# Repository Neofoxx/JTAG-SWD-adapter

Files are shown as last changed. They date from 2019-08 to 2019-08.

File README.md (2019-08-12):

# JTAG-SWD-adapter
Universal JTAG/SWD/UART adapter based on FT2232H

#### PCB view
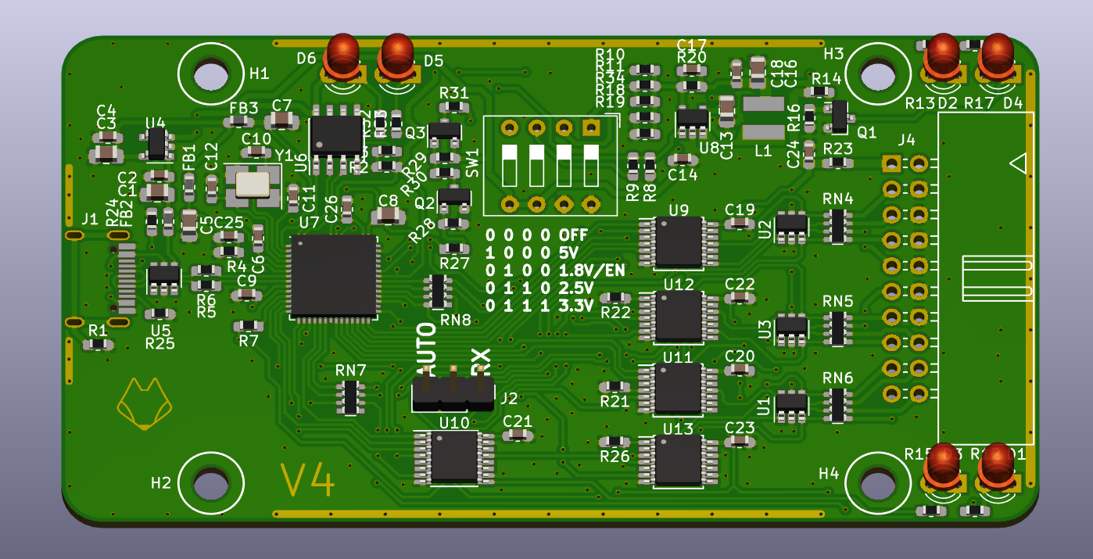
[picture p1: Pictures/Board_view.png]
PCB view


#### Finished product
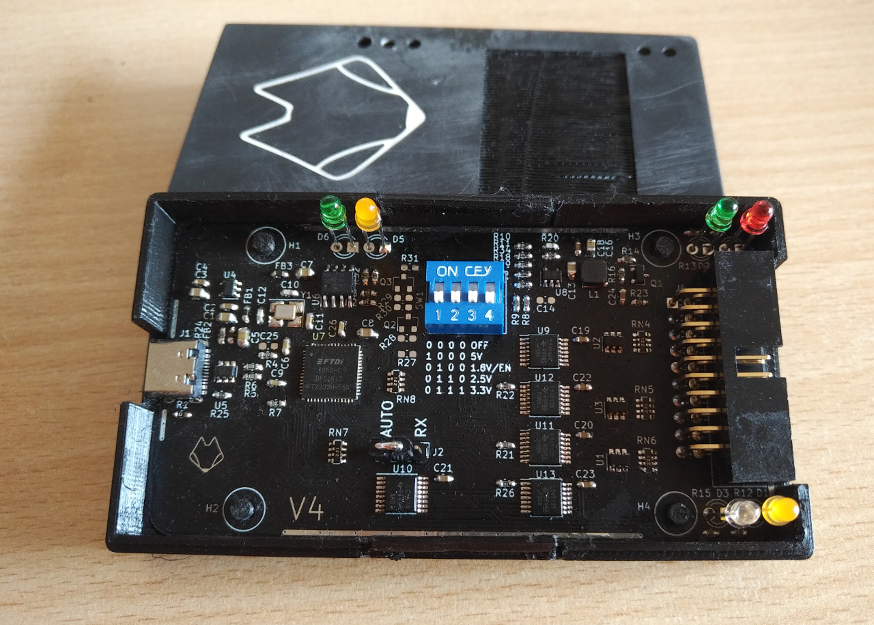
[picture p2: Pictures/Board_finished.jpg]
Finished view


### Pinout
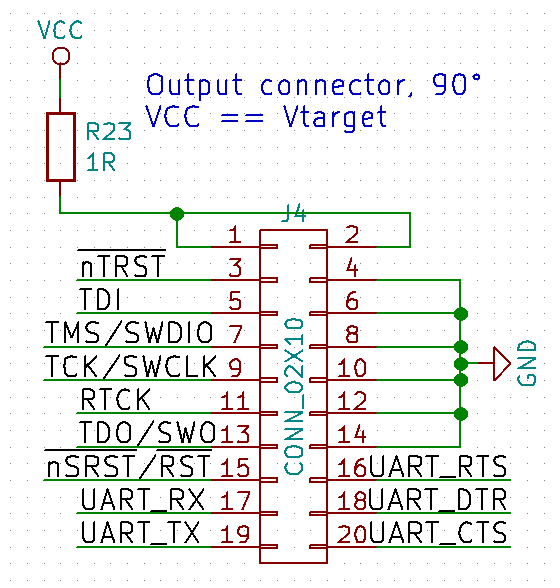
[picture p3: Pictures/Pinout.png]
Pinout


## Description
This is a universal JTAG/SWD/UART/SPI/... adapter based around the FT2232H chip.
This initially started based off the KT-Link specifications, but has since evolved into the following set of features:

- USB Type-C connector
- 1.8V - 5V traget supply
- JTAG and SWD support on channel A, UART support on channel B.
- ESD protection of USB and of target
- Integrated power section, to power target from the adapter (5V/3.3V/2.5V/1.8V available)
- Similar pinout to the standard found on commercial JTAG/SWD adapters, with the addition of UART pins
- JTAG/SWD programming with simultaneous UART communication
- LEDs for USB power, Target power, SWD interface, Activity, and RX&TX of the UART

The design has been tested and confirmed working with OpenOCD.
Tested targets so far have been STM32F1 (SWD), STM32F3 (SWD), ESP32 (JTAG), and PIC32MX (JTAG)

## Component selection & BOM

Components were selected based on the desire to try them out, usually based on price/performance. FT2232H and its support circuitry should not be changed, but other things (series resistors, LEDs, DCDC chip) can be changed & exprimented with without issue.

## Setup (1/2) - EEPROM

After soldering the board together and verifying for no shorts, plug the debugger into your computer, and verify that it shows up. With no parameters in the EEPROM, it should show up as a generic FT2232H Dual UART device.

You can find the relevant files in the Setup folder.

### Windows

Use the provided "Neofoxx FT-Prog template.xml".
- Connect the device to your computer. Verify that VCP drivers for FT2232H are installed
- Open FT-Prog. Click on "Devices" -> "Scan and Parse"
- The device should now show up
- Right clock on your device, and select "Apply template". Choose the template in the first step.
- Afterwards, right-click on the device again, and select "Program". Confirm again that you want to progam the device.
- After programming, unplug & re-plug your device. Wait for driver installation.
- In FT-Prog, perform another "Scan and Parse".
- Confirm the device has the proper parameters.
- Success!

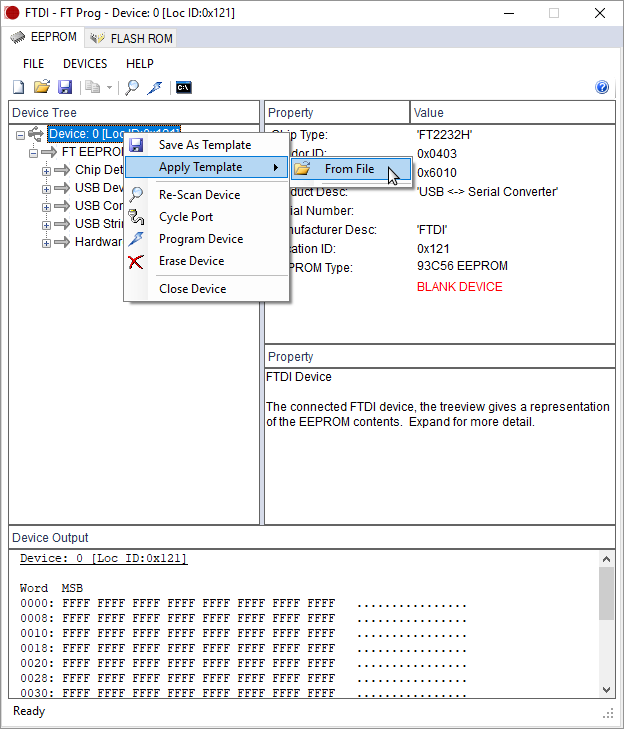
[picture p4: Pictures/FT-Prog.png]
FT-Prog


### Linux

- Use the provided "Neofoxx_ftdi_eeprom.conf". 
- (Feel free to change the serial number, but do not increase the number of characters)
- Install/build libftdi1 from https://www.intra2net.com/en/developer/libftdi/download.php
- (Link for reference, if you run into trouble: https://www.acmesystems.it/CM3-HOME_ft4232_setup )
- Flash the eeprom with the following command: `ftdi_eeprom --device i:0x0403:0x6010 --flash-eeprom Neofoxx_ftdi_eeprom.conf`
- Run the command again. Afterwards, unplug & re-plug the device.
- With dmesg or similar, you can check that the attached device now has the proper Manufacturer and Description string 
- Alternatively, in the examples folder, run the `eeprom` utility, and see what it outputs.

#### Known issues

- FT-Prog and ftdi_eeprom do not write 100% identical settings. The adapter will work nonetheless.
- If flashed with ftdi_eeprom, then checked in FT-Prog, the device will LOSE ITS PARAMETERS. In that case, upload them again in FT-Prog. If you don't check it in FT-Prog, it will work in Windows just fine. (Possible issue, that ftdi_eeprom doesn't write the eeprom type?)
- If you manage to mangle the parameters, and your VID/PID is suddenly 0000:0000, you can revive the device with a Windows box (virtualization won't work, unless you can pass a device with 0000:0000 to it).
- -> Connect the device to a Windows box, and force install the VCP drivers on the "Unknown device"
- -> This should then allow you to see the device in FT-Prog, and allow you to erase the eeprom and flash it with the proper parameters.

## Setup (2/2) - OpenOCD settings

- Copy the neofoxx.cfg file into your openocd scripts/interface/ftdi/ folder.

### Linux

- Done!

### Windows

- If you want to use the adapter with OpenOCD under Windows, you will have to change its drievr from the FTDI one a WinUSB one.
- Download zadig from here: https://zadig.akeo.ie/
- Run the tool.
- If necessary, in the Options menu, select "List All Devices"
- Select "Neofoxx JTAG/SWD adapter (Interface 0)"
- Select WinUSB, then click Replace Driver.
- Done!
- Note, if you have multiple adapters connected at the same time and want to use them, you have to do this on all of them.
- If the adapter suddenly stops working under Windows, fist check if the driver has changed. Windows have a nasty habit of changing things without telling you.

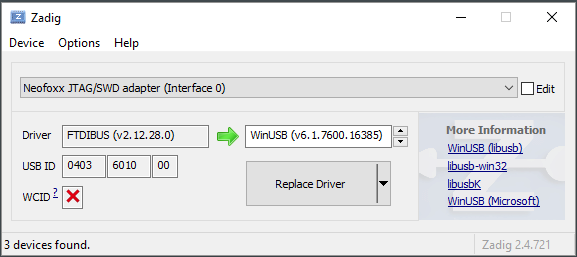
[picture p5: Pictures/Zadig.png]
Zadig


## Normal operation and things to look out for

- To use SWD with this board, you need to pass the proper flags to OpenOCD. Try something like this `openocd -f interface/ftdi/neofoxx.cfg -c "transport select swd" -f target/stm32f1x.cfg -c "adapter_khz 1000"`
- Because the board is compliant to the standard pinout, it will, when used in SWD mode, connect the TDO line to the RX of the UART channel, to be used as SWO.
- -> If this is undesired, the jumper on the board can be moved from "Auto" to "RX". This way, the UART RX pin will always be the RX pin, bypassing the switching of pins.
- The adapter includes a power section to power the target
- -> The maximum current draw is limited with a 1 ohm resistor, to protect the PC.
- -> When changing voltages, first turn the EN/1.8V pin to off, then set the voltage, then enable it again.
- -> When using 5V, disable the EN/1.8V switch first (the other two do not matter), then enable the 5V switch. Also in this case, if you make a mistake and short a high voltage onto the VTarget rail, your computer is at risk. There is some protection, but it's your computer. If you suspect this might happen, replace the 1 ohm resistor with an SMD fuse.
- The USB/Power LED shines when the USB cable is plugged in (5V is present)
- The VTarget LED shines when the voltage on VTarget is over 0.7V
- The SWD LED shines when the SWD interface is selected
- The Acivity light is SW driven from OpenOCD or others.

## Housing
The housing has been designed with latches, so it can be quickly opened and closed. 3D printing with PLA has given the best results so far.
Be warned, the housing was designed with minimal tolerances, so it might be a snug fit.

## Future improvements:

- Possibly split the two Vtarget pins into two separate pins - possibility of powering the target with say 5V, while communication works on 1.8V, etc.
- Instead of rounded corners, use inverted rounded corners, or no rounding at all. This would reduce waste during production of PCBs, since they could be panelized more easily (just V-cut, no mouse bites required)
- Fixup ftdi_eeprom & FT-Prog differences
- Update schematic to newer version of KiCad, and not use rescue symbols.
- Test the power section & enabling via the FTDI. As it is, that is UNTESTED

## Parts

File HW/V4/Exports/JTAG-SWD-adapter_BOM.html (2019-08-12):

Ref | Qnty | Value | Part | Footprint | Description | Vendor
C1, C3, C5, C7, C8 | 5 | 4u7 | Device:C | Capacitor_SMD:C_0805_2012Metric_Pad1.15x1.40mm_HandSolder | Unpolarized capacitor
C2, C4, C6, C9, C11, C14, C18, C19, C20, C21, C22, C23, C24, C26 | 14 | 100nF | Device:C | Capacitor_SMD:C_0603_1608Metric_Pad1.05x0.95mm_HandSolder | Unpolarized capacitor
C10, C12 | 2 | 27pF | Device:C | Capacitor_SMD:C_0603_1608Metric_Pad1.05x0.95mm_HandSolder | Unpolarized capacitor
C13, C16 | 2 | 4.7uF | Device:C | Capacitor_SMD:C_0805_2012Metric_Pad1.15x1.40mm_HandSolder | Unpolarized capacitor
C17, C25 | 2 | DNS | Device:C | Capacitor_SMD:C_0603_1608Metric_Pad1.05x0.95mm_HandSolder | Unpolarized capacitor
D1, D2, D3, D4, D5, D6 | 6 | LED | JTAG-SWD-adapter-rescue:LED | LED_THT:LED_D3.0mm
FB1, FB3 | 2 | 600R, 1A | Device:Ferrite_Bead_Small | Inductor_SMD:L_0603_1608Metric_Pad1.05x0.95mm_HandSolder | Ferrite bead, small symbol
FB2 | 1 | 220R, 2.5A | Device:Ferrite_Bead_Small | Inductor_SMD:L_0603_1608Metric_Pad1.05x0.95mm_HandSolder | Ferrite bead, small symbol
H1, H2, H3, H4 | 4 | MountingHole | Mechanical:MountingHole | MountingHole:MountingHole_3.2mm_M3 | Mounting Hole without connection
J1 | 1 | USB_C_Receptacle_USB2.0 | Connector:USB_C_Receptacle_USB2.0 | KiCAD library:Jing USB C 2.0 16pin receptable | USB 2.0-only Type-C Receptacle connector
J2 | 1 | Conn_01x03_Male | Connector:Conn_01x03_Male | Connector_PinHeader_2.54mm:PinHeader_1x03_P2.54mm_Vertical | Generic connector, single row, 01x03, script generated (kicad-library-utils/schlib/autogen/connector/)
J4 | 1 | CONN_02X10 | JTAG-SWD-adapter-rescue:CONN_02X10 | Connector_Multicomp:Multicomp_MC9A22-2034_2x10_P2.54mm_Horizontal
L1 | 1 | 1.5uH | Device:L | KiCAD library:SMNR4018_(1616FPS) | Inductor
MARK1 | 1 | LOGO | KiCAD library symbols:LOGO | KiCAD library:FOX_LOGO_MASK
Q1, Q2 | 2 | BC847 | Transistor_BJT:BC847 | Package_TO_SOT_SMD:SOT-23 | 0.1A Ic, 45V Vce, NPN Transistor, SOT-23
Q3 | 1 | BC857 | Transistor_BJT:BC857 | Package_TO_SOT_SMD:SOT-23 | 0.1A Ic, 45V Vce, PNP Transistor, SOT-23
R1 | 1 | 0R | Device:R | Resistor_SMD:R_0603_1608Metric_Pad1.05x0.95mm_HandSolder | Resistor
R2, R7, R27, R30 | 4 | 10k | Device:R | Resistor_SMD:R_0603_1608Metric_Pad1.05x0.95mm_HandSolder | Resistor
R3 | 1 | 2k | Device:R | Resistor_SMD:R_0603_1608Metric_Pad1.05x0.95mm_HandSolder | Resistor
R4 | 1 | 12k | Device:R | Resistor_SMD:R_0603_1608Metric_Pad1.05x0.95mm_HandSolder | Resistor
R5, R6 | 2 | 10R | Device:R | Resistor_SMD:R_0603_1608Metric_Pad1.05x0.95mm_HandSolder | Resistor
R8, R14, R16, R28, R29 | 5 | 100k | Device:R | Resistor_SMD:R_0603_1608Metric_Pad1.05x0.95mm_HandSolder | Resistor
R9, R12, R13, R15, R17, R21, R22, R26, R31, R32, R33 | 11 | 1k | JTAG-SWD-adapter-rescue:R | Resistor_SMD:R_0603_1608Metric_Pad1.05x0.95mm_HandSolder
R10 | 1 | 180k | JTAG-SWD-adapter-rescue:R | Resistor_SMD:R_0603_1608Metric_Pad1.05x0.95mm_HandSolder
R11 | 1 | 470k | JTAG-SWD-adapter-rescue:R | Resistor_SMD:R_0603_1608Metric_Pad1.05x0.95mm_HandSolder
R18, R19, R20 | 3 | 220k | JTAG-SWD-adapter-rescue:R | Resistor_SMD:R_0603_1608Metric_Pad1.05x0.95mm_HandSolder
R23 | 1 | 1R | Device:R | Resistor_SMD:R_0603_1608Metric_Pad1.05x0.95mm_HandSolder | Resistor
R24, R25 | 2 | 5k1 | Device:R | Resistor_SMD:R_0603_1608Metric_Pad1.05x0.95mm_HandSolder | Resistor
R34 | 1 | 330k | JTAG-SWD-adapter-rescue:R | Resistor_SMD:R_0603_1608Metric_Pad1.05x0.95mm_HandSolder
RN1, RN2, RN3 | 3 | 4x470k | JTAG-SWD-adapter-rescue:R_Pack04 | Resistor_SMD:R_Array_Convex_4x0603
RN4, RN5, RN6, RN7, RN8 | 5 | 4x220R | JTAG-SWD-adapter-rescue:R_Pack04 | Resistor_SMD:R_Array_Convex_4x0603
SW1 | 1 | SW_DIP_x04 | Switch:SW_DIP_x04 | Button_Switch_THT:SW_DIP_SPSTx04_Slide_9.78x12.34mm_W7.62mm_P2.54mm | 4x DIP Switch, Single Pole Single Throw (SPST) switch, small symbol
U1, U2, U3, U5 | 4 | SRV05-4 | Power_Protection:SRV05-4 | Package_TO_SOT_SMD:SOT-23-6 | ESD Protection Diodes with Low Clamping Voltage, SOT-23-6
U4 | 1 | LN1134A332MR-G | Regulator_Linear:AP2112K-3.3 | Package_TO_SOT_SMD:SOT-23-5 | 600mA low dropout linear regulator, with enable pin, 3.8V-6V input voltage range, 3.3V fixed positive output, SOT-23-5 package
U6 | 1 | 93LCxxB | Memory_EEPROM:93LCxxB | Package_SO:SOIC-8_3.9x4.9mm_P1.27mm | Serial EEPROM, 93 Series, 2.5V, DIP-8/SOIC-8
U7 | 1 | FT2232H-56Q | KiCAD library symbols:FT2232H-56Q | Package_DFN_QFN:QFN-56-1EP_8x8mm_P0.5mm_EP5.6x5.6mm
U8 | 1 | BL8028 | KiCAD library symbols:BL8028 | Package_TO_SOT_SMD:SOT-23-5
U9, U11, U12, U13 | 4 | 74LVC125 | 74xx:74LVC125 | Package_SO:TSSOP-14_4.4x5mm_P0.65mm | Quad buffer 3-State outputs
U10 | 1 | 74LVC157A | JTAG-SWD-adapter-rescue:74LS157-RESCUE-JTAG-SWD-adapter | Package_SO:TSSOP-16_4.4x5mm_P0.65mm
Y1 | 1 | 12MHz | Device:Crystal_GND24 | Crystal:Crystal_SMD_3225-4Pin_3.2x2.5mm_HandSoldering | Four pin crystal, GND on pins 2 and 4

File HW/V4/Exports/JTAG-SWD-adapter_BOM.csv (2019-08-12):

Source: | /home/neofoxx/Projects/HW/JTAG-SWD-adapter/HW/V4/JTAG-SWD-adapter.sch
Date: | ned 11 avg 2019 10:19:47 CEST
Tool: | Eeschema 5.0.2-bee76a0~70~ubuntu18.04.1
Generator: | /usr/share/kicad/plugins/bom_csv_grouped_by_value_with_fp.py
Component Count: | 103
Ref | Qnty | Value | Cmp name | Footprint | Description | Vendor
C1, C3, C5, C7, C8, | 5 | 4u7 | C | Capacitor_SMD:C_0805_2012Metric_Pad1.15x1.40mm_HandSolder | Unpolarized capacitor
C12, C10, | 2 | 27pF | C | Capacitor_SMD:C_0603_1608Metric_Pad1.05x0.95mm_HandSolder | Unpolarized capacitor
C16, C13, | 2 | 4.7uF | C | Capacitor_SMD:C_0805_2012Metric_Pad1.15x1.40mm_HandSolder | Unpolarized capacitor
C24, C2, C4, C6, C9, C11, C26, C18, C14, C20, C19, C23, C22, C21, | 14 | 100nF | C | Capacitor_SMD:C_0603_1608Metric_Pad1.05x0.95mm_HandSolder
C25, C17, | 2 | DNS | C | Capacitor_SMD:C_0603_1608Metric_Pad1.05x0.95mm_HandSolder | Unpolarized capacitor
D1, D2, D4, D3, D5, D6, | 6 | LED | LED | LED_THT:LED_D3.0mm
FB1, FB3, | 2 | 600R, 1A | Ferrite_Bead_Small | Inductor_SMD:L_0603_1608Metric_Pad1.05x0.95mm_HandSolder | Ferrite bead, small symbol
FB2, | 1 | 220R, 2.5A | Ferrite_Bead_Small | Inductor_SMD:L_0603_1608Metric_Pad1.05x0.95mm_HandSolder | Ferrite bead, small symbol
H1, H2, H4, H3, | 4 | MountingHole | MountingHole | MountingHole:MountingHole_3.2mm_M3 | Mounting Hole without connection
J1, | 1 | USB_C_Receptacle_USB2.0 | USB_C_Receptacle_USB2.0 | KiCAD library:Jing USB C 2.0 16pin receptable | USB 2.0-only Type-C Receptacle connector
J2, | 1 | Conn_01x03_Male | Conn_01x03_Male | Connector_PinHeader_2.54mm:PinHeader_1x03_P2.54mm_Vertical | Generic connector, single row, 01x03, script generated (kicad-library-utils/schlib/autogen/connector/)
J4, | 1 | CONN_02X10 | CONN_02X10 | Connector_Multicomp:Multicomp_MC9A22-2034_2x10_P2.54mm_Horizontal
L1, | 1 | 1.5uH | L | KiCAD library:SMNR4018_(1616FPS) | Inductor
MARK1, | 1 | LOGO | LOGO | KiCAD library:FOX_LOGO_MASK
Q1, Q2, | 2 | BC847 | BC847 | Package_TO_SOT_SMD:SOT-23 | 0.1A Ic, 45V Vce, NPN Transistor, SOT-23
Q3, | 1 | BC857 | BC857 | Package_TO_SOT_SMD:SOT-23 | 0.1A Ic, 45V Vce, PNP Transistor, SOT-23
R1, | 1 | 0R | R | Resistor_SMD:R_0603_1608Metric_Pad1.05x0.95mm_HandSolder | Resistor
R3, | 1 | 2k | R | Resistor_SMD:R_0603_1608Metric_Pad1.05x0.95mm_HandSolder | Resistor
R4, | 1 | 12k | R | Resistor_SMD:R_0603_1608Metric_Pad1.05x0.95mm_HandSolder | Resistor
R6, R5, | 2 | 10R | R | Resistor_SMD:R_0603_1608Metric_Pad1.05x0.95mm_HandSolder | Resistor
R7, R2, R30, R27, | 4 | 10k | R | Resistor_SMD:R_0603_1608Metric_Pad1.05x0.95mm_HandSolder | Resistor
R10, | 1 | 180k | R | Resistor_SMD:R_0603_1608Metric_Pad1.05x0.95mm_HandSolder
R11, | 1 | 470k | R | Resistor_SMD:R_0603_1608Metric_Pad1.05x0.95mm_HandSolder
R12, R13, R17, R15, R32, R33, R9, R31, R21, R22, R26, | 11 | 1k | R | Resistor_SMD:R_0603_1608Metric_Pad1.05x0.95mm_HandSolder
R14, R16, R8, R29, R28, | 5 | 100k | R | Resistor_SMD:R_0603_1608Metric_Pad1.05x0.95mm_HandSolder | Resistor
R20, R18, R19, | 3 | 220k | R | Resistor_SMD:R_0603_1608Metric_Pad1.05x0.95mm_HandSolder
R23, | 1 | 1R | R | Resistor_SMD:R_0603_1608Metric_Pad1.05x0.95mm_HandSolder | Resistor
R24, R25, | 2 | 5k1 | R | Resistor_SMD:R_0603_1608Metric_Pad1.05x0.95mm_HandSolder | Resistor
R34, | 1 | 330k | R | Resistor_SMD:R_0603_1608Metric_Pad1.05x0.95mm_HandSolder
RN1, RN2, RN3, | 3 | 4x470k | R_Pack04 | Resistor_SMD:R_Array_Convex_4x0603
RN6, RN5, RN4, RN7, RN8, | 5 | 4x220R | R_Pack04 | Resistor_SMD:R_Array_Convex_4x0603
SW1, | 1 | SW_DIP_x04 | SW_DIP_x04 | Button_Switch_THT:SW_DIP_SPSTx04_Slide_9.78x12.34mm_W7.62mm_P2.54mm | 4x DIP Switch, Single Pole Single Throw (SPST) switch, small symbol
U2, U3, U1, U5, | 4 | SRV05-4 | SRV05-4 | Package_TO_SOT_SMD:SOT-23-6 | ESD Protection Diodes with Low Clamping Voltage, SOT-23-6
U4, | 1 | LN1134A332MR-G | AP2112K-3.3 | Package_TO_SOT_SMD:SOT-23-5 | 600mA low dropout linear regulator, with enable pin, 3.8V-6V input voltage range, 3.3V fixed positive output, SOT-23-5 package
U6, | 1 | 93LCxxB | 93LCxxB | Package_SO:SOIC-8_3.9x4.9mm_P1.27mm | Serial EEPROM, 93 Series, 2.5V, DIP-8/SOIC-8
U7, | 1 | FT2232H-56Q | FT2232H-56Q | Package_DFN_QFN:QFN-56-1EP_8x8mm_P0.5mm_EP5.6x5.6mm
U8, | 1 | BL8028 | BL8028 | Package_TO_SOT_SMD:SOT-23-5
U9, U11, U12, U13, | 4 | 74LVC125 | 74LVC125 | Package_SO:TSSOP-14_4.4x5mm_P0.65mm | Quad buffer 3-State outputs
U10, | 1 | 74LVC157A | 74LS157-RESCUE-JTAG-SWD-adapter | Package_SO:TSSOP-16_4.4x5mm_P0.65mm
Y1, | 1 | 12MHz | Crystal_GND24 | Crystal:Crystal_SMD_3225-4Pin_3.2x2.5mm_HandSoldering | Four pin crystal, GND on pins 2 and 4

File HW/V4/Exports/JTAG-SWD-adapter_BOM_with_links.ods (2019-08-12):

Source: | /home/neofoxx/Projects/HW/JTAG-SWD-adapter/HW/V4/JTAG-SWD-adapter.sch
Date: | ned 11 avg 2019 10:19:47 CEST
Tool: | Eeschema 5.0.2-bee76a0~70~ubuntu18.04.1
Generator: | /usr/share/kicad/plugins/bom_csv_grouped_by_value_with_fp.py
Component Count: | 103 |  |  | Components are listed as they are used on prototypes
Ref | Qnty | Value | Description | Link
C1, C3, C5, C7, C8, | 5 | 4u7 | Capacitor, 0805 | https://lcsc.com/product-detail/Multilayer-Ceramic-Capacitors-MLCC-SMD-SMT_SAMSUNG_CL21A475KAQNNNE_4-7uF-475-10-25V_C1779.html
C12, C10, | 2 | 27pF | Capacitor, 0603 | https://lcsc.com/product-detail/Others_Murata-Electronics-GRM1885C1H270FA01D_C162215.html
C16, C13, | 2 | 4.7uF | Capacitor, 0805 | https://lcsc.com/product-detail/Multilayer-Ceramic-Capacitors-MLCC-SMD-SMT_SAMSUNG_CL21A475KAQNNNE_4-7uF-475-10-25V_C1779.html
C24, C2, C4, C6, C9, C11, C26, C18, C14, C20, C19, C23, C22, C21, | 14 | 100nF | Capacitor, 0603 | https://lcsc.com/product-detail/Multilayer-Ceramic-Capacitors-MLCC-SMD-SMT_SAMSUNG_CL10B104KB8NNNC_100nF-104-10-50V_C1591.html
C25, C17, | 2 | DNS | Capacitor, 0603
D1, D2, D4, D3, D5, D6, | 6 | LED | 3mm through hole LED | Any 3mm LED with matte lens (clear works too, just doesn’t look as nice)
FB1, FB3, | 2 | 600R, 1A | Ferrite bead, 0603 | https://lcsc.com/product-detail/Ferrite-Beads-And-Chips_TDK_MPZ1608S601ATA00_600R-25-at100MHz_C107335.html
FB2, | 1 | 220R, 2.5A | Ferrite bead, 0603 | https://lcsc.com/product-detail/Ferrite-Beads-And-Chips_muRata_BLM18SG221TN1D_220R-25_C88988.html
J1, | 1 | USB_C_Receptacle_USB2.0 | USB C connector | https://lcsc.com/product-detail/USB-Type-C_MC-311D_C136423.html
J2, | 1 | Conn_01x03_Male | 3-pin header | Any pin header + jumper
J4, | 1 | CONN_02X10 | 20pin header, 90° | https://www.tme.eu/en/details/t821-1-20-r1/idc-connectors/amphenol/t821120a1r100ceu/
L1, | 1 | 1.5uH | Coil for DCDC | https://lcsc.com/product-detail/Power-Inductors_Shun-Xiang-Nuo-Elec-SMNR4018-1R5MT_C135252.html
Q1, Q2, | 2 | BC847 | NPN transistor | https://uk.farnell.com/on-semiconductor/bc847blt3g/transistor-bipol-npn-45v-sot-23/dp/2533307
Q3, | 1 | BC857 | PNP transistor | https://uk.farnell.com/on-semiconductor/bc857blt1g/transistor-pnp-sot-23/dp/1459044
R1, | 1 | 0R | Resistor, 0603 | https://uk.farnell.com/multicomp/mcwr06x000-ptl/res-0r0-0-1w-jumper/dp/2447743
R3, | 1 | 2k | Resistor, 0603 | https://lcsc.com/product-detail/Chip-Resistor-Surface-Mount_2KR-2001-1_C105576.html
R4, | 1 | 12k | Resistor, 0603 | https://lcsc.com/product-detail/Chip-Resistor-Surface-Mount_12KR-1202-1_C114659.html
R6, R5, | 2 | 10R | Resistor, 0603 | https://uk.farnell.com/multicomp/mcmr06x10r0ftl/res-10r-1-0-1w-0603-ceramic/dp/2073361
R7, R2, R30, R27, | 4 | 10k | Resistor, 0603 | https://lcsc.com/product-detail/Chip-Resistor-Surface-Mount_10KR-1002-1_C98220.html
R10, | 1 | 180k | Resistor, 0603 | https://lcsc.com/product-detail/Chip-Resistor-Surface-Mount_Uniroyal-Elec-0603WAF1803T5E_C22827.html
R11, | 1 | 470k | Resistor, 0603 | https://lcsc.com/product-detail/Chip-Resistor-Surface-Mount_470KR-4703-1_C114622.html
R12, R13, R17, R15, R32, R33, R9, R31, R21, R22, R26, | 11 | 1k | Resistor, 0603 | https://lcsc.com/product-detail/Chip-Resistor-Surface-Mount_1KR-1001-1_C22548.html
R14, R16, R8, R29, R28, | 5 | 100k | Resistor, 0603 | https://lcsc.com/product-detail/Chip-Resistor-Surface-Mount_100KR-1003-1_C14675.html
R20, R18, R19, | 3 | 220k | Resistor, 0603 | https://lcsc.com/product-detail/Chip-Resistor-Surface-Mount_220KR-220K-1_C123420.html
R23, | 1 | 1R | Resistor, 0603 | https://uk.farnell.com/multicomp/mcwr06w1r00ftl/res-1r-1-0-1w-0603-thick-film/dp/2447289
R24, R25, | 2 | 5k1 | Resistor, 0603 | https://lcsc.com/product-detail/Chip-Resistor-Surface-Mount_5-1KR-5101-1_C105580.html
R34, | 1 | 330k | Resistor, 0603 | https://lcsc.com/product-detail/Chip-Resistor-Surface-Mount_330KR-3303-1_C114618.html
RN1, RN2, RN3, | 3 | 4x470k | Resistor, 4*0603 | https://lcsc.com/product-detail/Resistor-Networks-Arrays_Uniroyal-Elec-4D03WGJ0474T5E_C12026.html
RN6, RN5, RN4, RN7, RN8, | 5 | 4x220R | Resistor, 4*0603 | https://lcsc.com/product-detail/Resistor-Networks-Arrays_Uniroyal-Elec-4D03WGJ0221T5E_C29719.html
SW1, | 1 | SW_DIP_x04 | Dip switch, though hole, 4 position | https://lcsc.com/product-detail/DIP-Switches_Dongguan-Guangzhu-Industrial-Dongguan-Guangzhu-Industrial-Dongguan-Guangzhu-Industrial-DIP-switch-Dip-Switch-DSWB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
U2, U3, U1, U5, | 4 | SRV05-4 | ESD diodes | https://lcsc.com/product-detail/TVS_SRV05-4_C127538.html
U4, | 1 | LN1134A332MR-G | 3.3V Linear regulator | https://lcsc.com/product-detail/Low-Dropout-Regulators-LDO_NATLINEAR-LN1134A332MR-G_C141419.html
U6, | 1 | 93LCxxB | EEPROM | https://uk.farnell.com/microchip/93lc56b-i-sn/serial-eeprom-2kbit-2mhz-soic/dp/9758259
U7, | 1 | FT2232H-56Q | FTDI chip | https://uk.farnell.com/ftdi/ft2232h-56q-reel/interface-bridge-usb-uart-fifo/dp/2535722
U8, | 1 | BL8028 | DCDC step-down | https://lcsc.com/product-detail/DC-DC-Converters_Shanghai-Belling-BL8028CB5TR_C266177.html
U9, U11, U12, U13, | 4 | SN74LV4T125 | Voltage translators | https://uk.farnell.com/texas-instruments/sn74lv4t125pwr/buffer-translator-3-state-o-p/dp/3006795
U10, | 1 | SN74LVC157A | Mux chip | https://uk.farnell.com/texas-instruments/sn74lvc157apw/ic-data-selector-mux-74lvc157/dp/9592717
Y1, | 1 | 12MHz | Crystal | https://uk.farnell.com/multicomp/mcsjk-7u-12-00-10-10-80-b-10/crystal-12mhz-10pf-3-2mm-x-2-5mm/dp/2853914

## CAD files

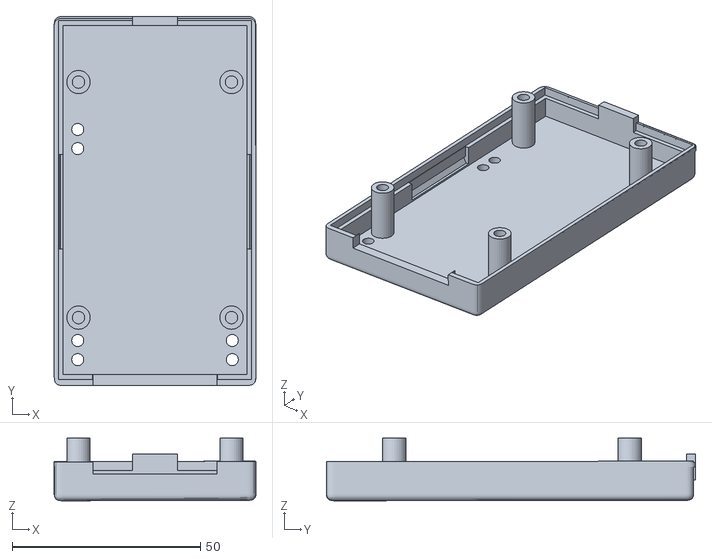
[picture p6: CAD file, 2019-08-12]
Housing/V4/Exports/ProgBox-Case_top.stl
53.6 x 97.9 x 16.6

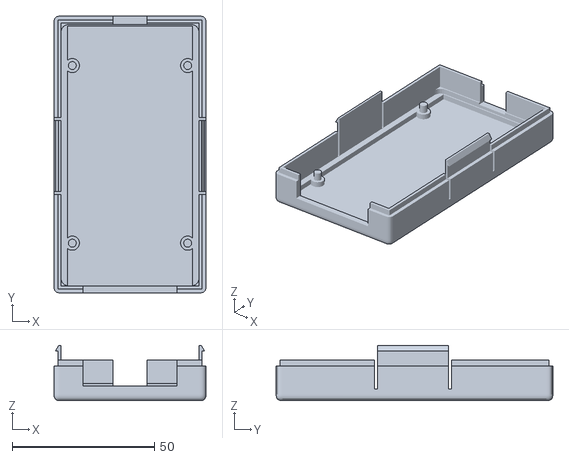
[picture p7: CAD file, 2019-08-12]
Housing/V4/Exports/ProgBox-Case_bottom.stl
53.5 x 97.4 x 19.5

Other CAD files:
Housing/V4/ProgBox.blend

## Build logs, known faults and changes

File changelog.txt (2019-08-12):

V1:

- An add-on board for the FT2232H-56Q Mini-Module
- Includes only voltage translators, series/pull-down resistors and status LEDs

Changelog for V2:

- V2 was never finished.
- Idea was to add ESD protection, and a PowerSupply stage
-- ESD - quad ESD diodes, for 5V max.
-- Power supply - 600mA Step-down DCDC, 5V/3.3V/2.5V/1.8V options.
-- Selectable through DIP switched on the inside.

Changes from V2 to V3:

- Raw FT2232 chip
- ESD now SRV05-4 instead of PGB1010603 (3pF instead of 0.4pF)
- USB C CONNECTOR!
- Through hole LEDs - saves a fortune on light guides
- Added open soldermask on select edges - should help with ESD
- Power supply section added for powering the target
- Most resistors changed to resistor array (4x0603)

Changelog for V4:

- DCDC converter in the power supply changed to a more suitable one.
- Fixed wiriing error on the USB connector
- Added status LEDs for the second UART channel (RX&TX LEDs)
- Removed dual footprints for the EEPROM

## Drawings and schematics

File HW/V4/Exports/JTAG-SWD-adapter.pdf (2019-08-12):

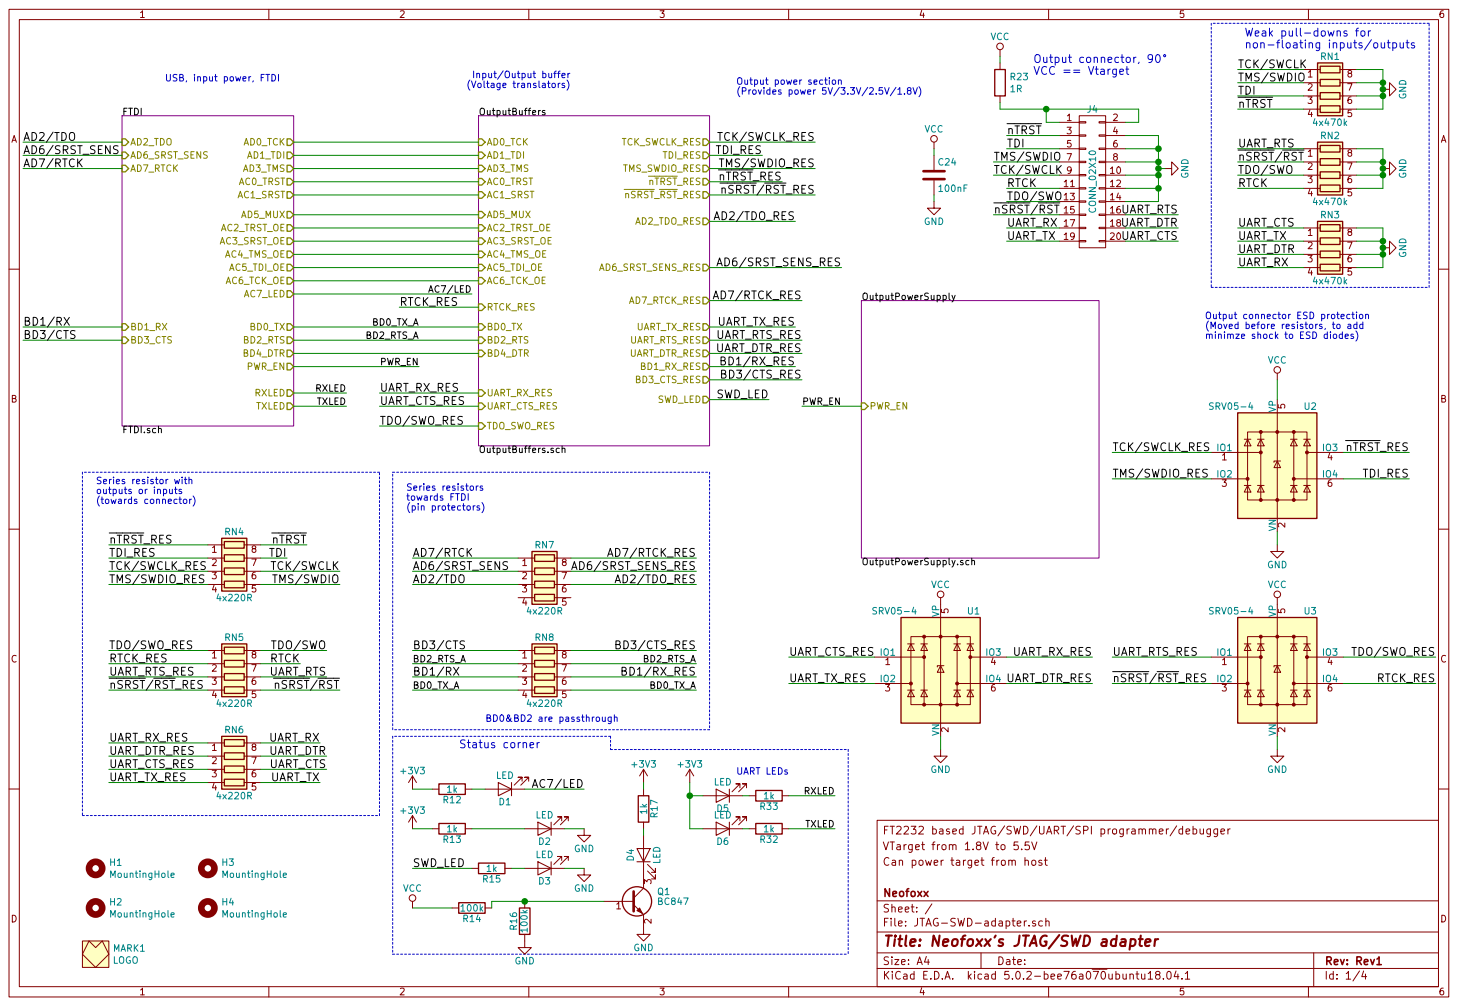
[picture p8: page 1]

Weak pull-downs for

TDI TMS/SWDIO | 1

TDI_RES

BD2_RTS_A | UART_RTS_RES

(Moved before resistors, to add
minimze shock to ESD diodes)

UART_DTR_RES

Series resistors
towards FTDI (pin protectors)

FT2232 based JTAG/SWD/UART/SPI programmer/debugger
VTarget from 1.8V to 5.5V
File: JTAG-SWD-adapter.sch Sheet: / Neofoxx Can power target from host

Id: 1/4 Title: Neofoxx's JTAG/SWD adapter

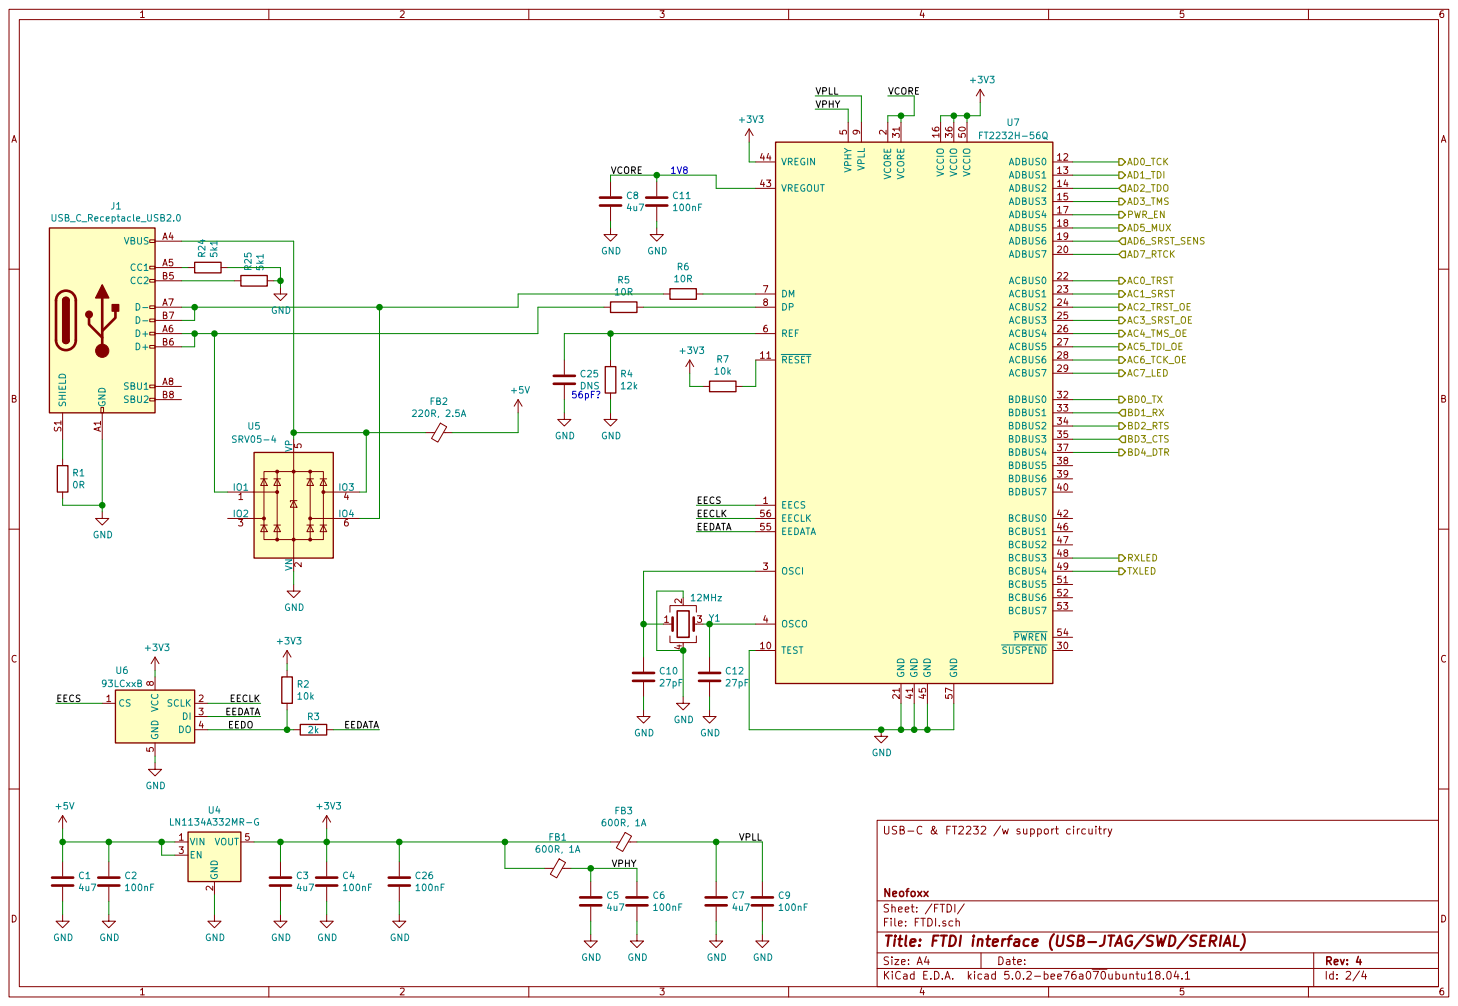
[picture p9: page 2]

Id: 2/4 Title: FTDI interface (USB-JTAG/SWD/SERIAL) File: FTDI.sch Sheet: /FTDI/ Neofoxx USB-C & FT2232 /w support circuitry R1
0R GND

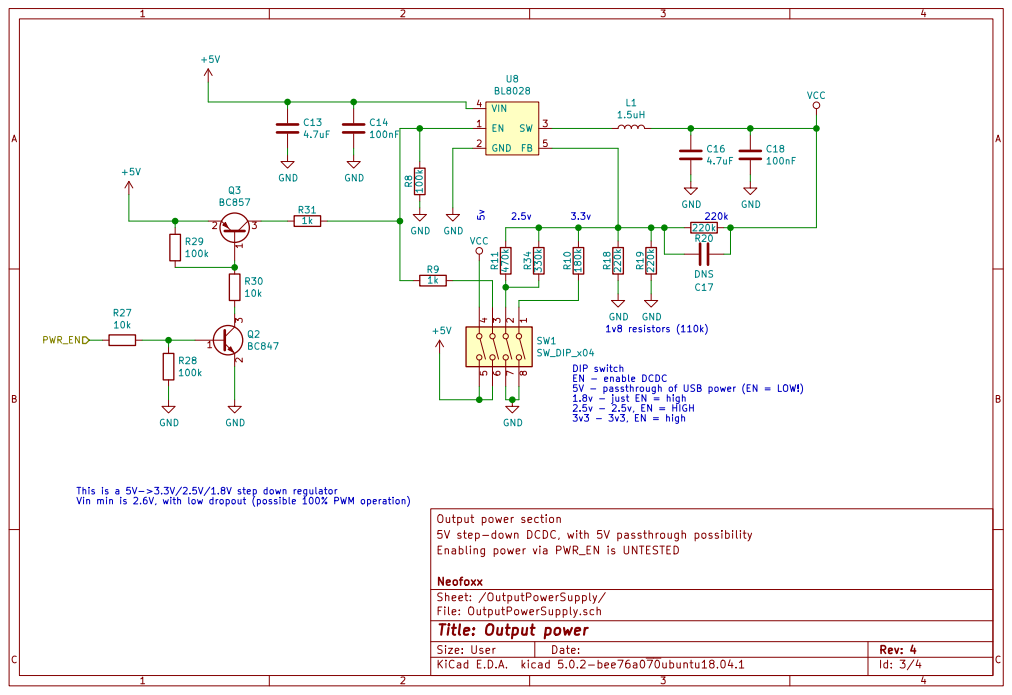
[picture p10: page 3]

8 SW1 SW_DIP_x04 R8 100k GND GND GND GND GND

Vin min is 2.6V, with low dropout (possible 100% PWM operation) 1

DIP switch EN - enable DCDC
5V - passthrough of USB power (EN = LOW!)
1.8v - just EN = high
2.5v - 2.5v, EN = HIGH
3v3 - 3v3, EN = high

This is a 5V->3.3V/2.5V/1.8V step down regulator

Output power section
5V step-down DCDC, with 5V passthrough possibility
Sheet: /OutputPowerSupply/ Neofoxx Enabling power via PWR_EN is UNTESTED

File: OutputPowerSupply.sch
Id: 3/4 Title: Output power

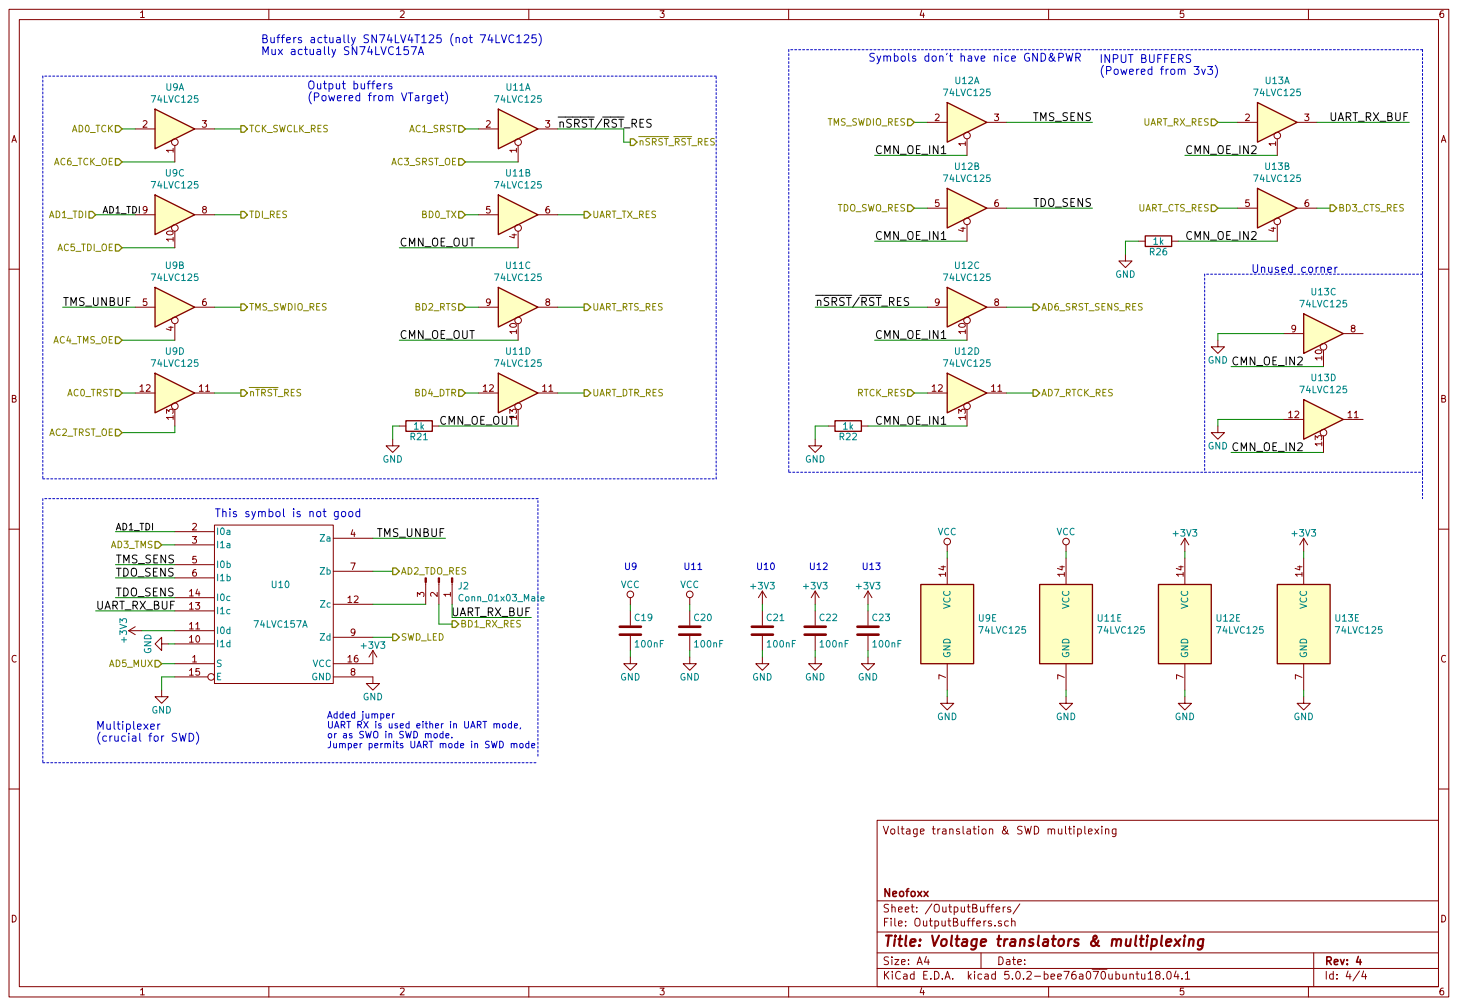
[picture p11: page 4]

Added jumper UART RX is used either in UART mode, or as SWO in SWD mode. Jumper permits UART mode in SWD mode

File: OutputBuffers.sch
Id: 4/4 Title: Voltage translators & multiplexing

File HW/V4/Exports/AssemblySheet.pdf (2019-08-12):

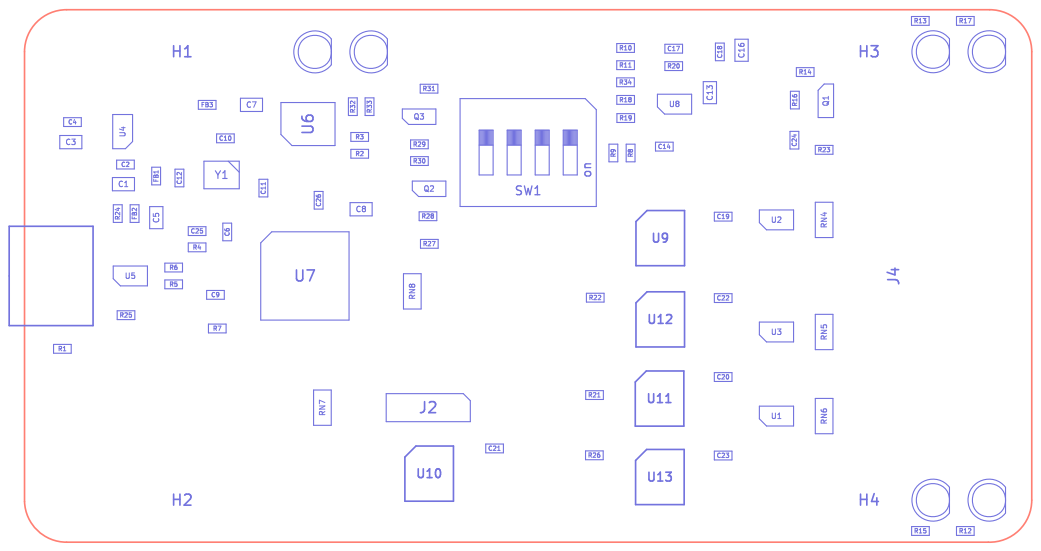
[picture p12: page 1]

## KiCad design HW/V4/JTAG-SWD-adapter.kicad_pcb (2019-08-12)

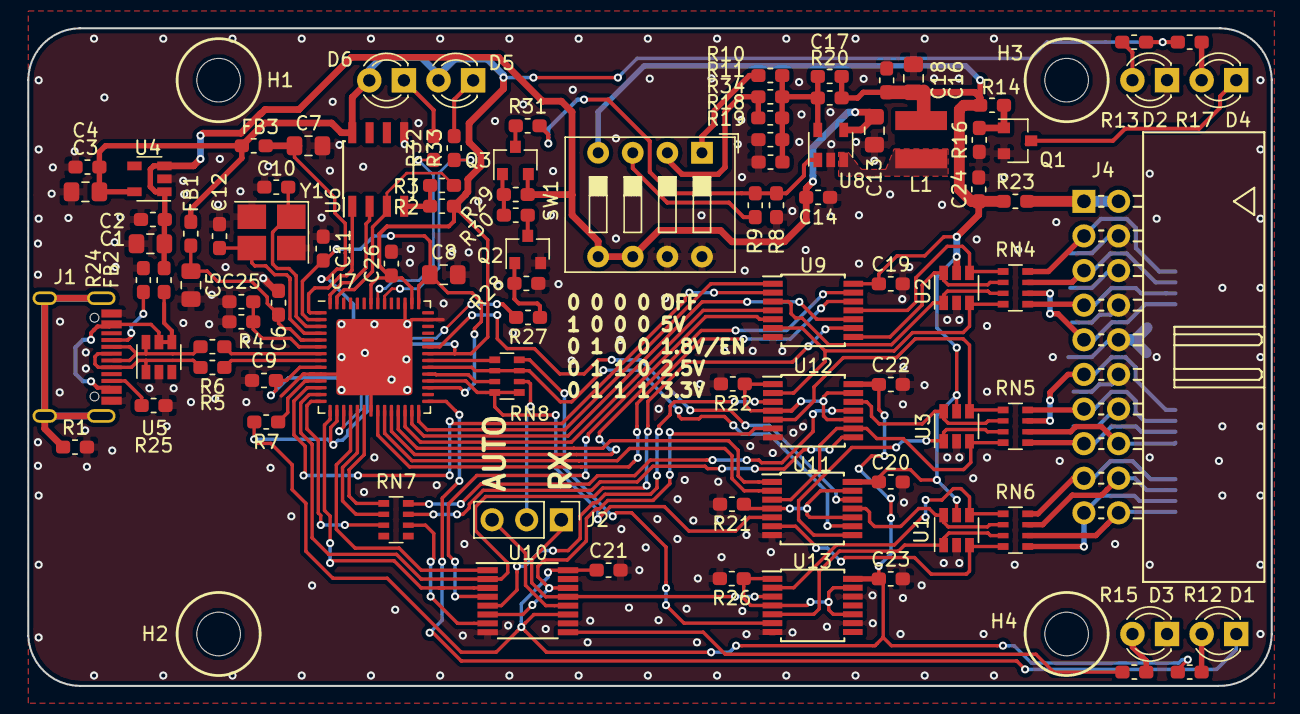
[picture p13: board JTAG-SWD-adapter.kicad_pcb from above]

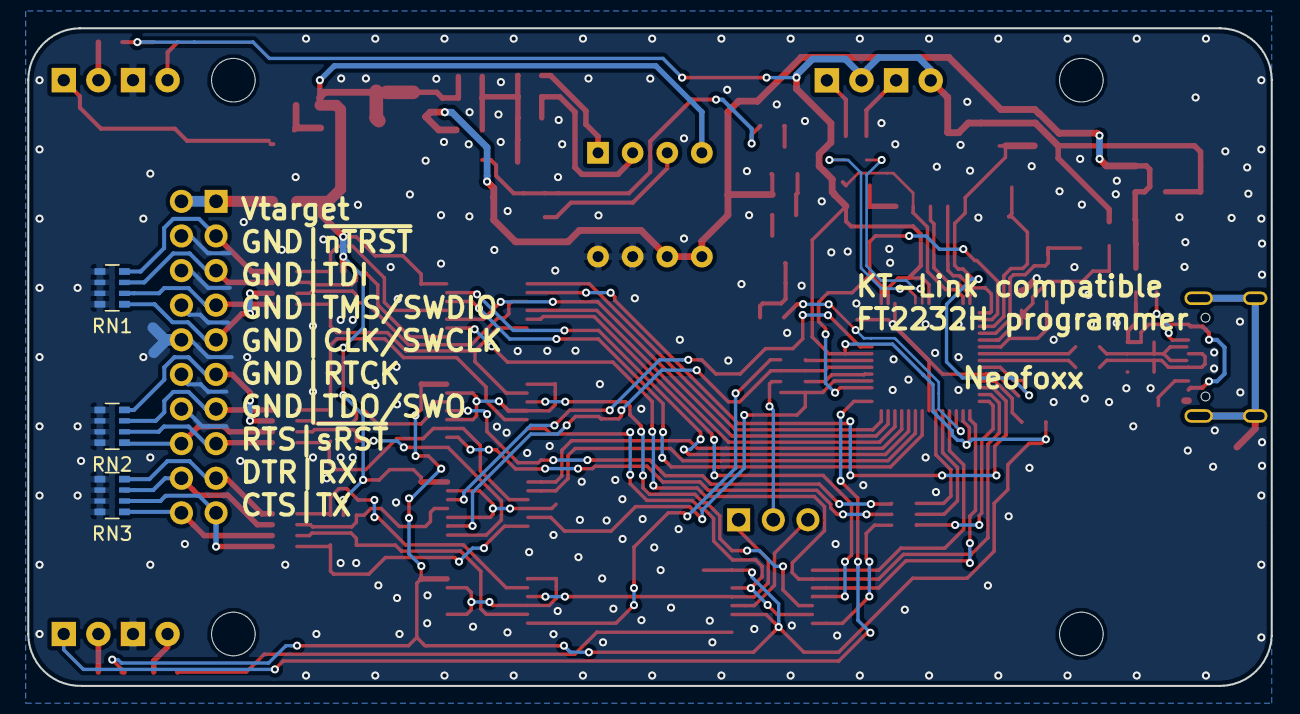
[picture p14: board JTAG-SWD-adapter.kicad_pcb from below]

Board: 2 copper layers, 91.2 x 48.3 mm, 103 parts (3 on the bottom side), 103 nets.

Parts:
C1, C3, C5, C7, C8: 4u7; C_0805_2012Metric_Pad1.15x1.40mm_HandSolder
C2, C4, C6, C9, C11, C14, C18, C19, C20, C21, C22, C23, C24, C26: 100nF; C_0603_1608Metric_Pad1.05x0.95mm_HandSolder
C10, C12: 27pF; C_0603_1608Metric_Pad1.05x0.95mm_HandSolder
C13, C16: 4.7uF; C_0805_2012Metric_Pad1.15x1.40mm_HandSolder
C17, C25: DNS; C_0603_1608Metric_Pad1.05x0.95mm_HandSolder
D1, D2, D3, D4, D5, D6: LED; LED_D3.0mm
FB1, FB3: 600R, 1A; L_0603_1608Metric_Pad1.05x0.95mm_HandSolder
FB2: 220R, 2.5A; L_0603_1608Metric_Pad1.05x0.95mm_HandSolder
H1, H2, H3, H4: MountingHole; MountingHole_3.2mm_M3
J1: USB_C_Receptacle_USB2.0; Jing USB C 2.0 16pin receptable
J2: Conn_01x03_Male; PinHeader_1x03_P2.54mm_Vertical
J4: CONN_02X10; Multicomp_MC9A22-2034_2x10_P2.54mm_Horizontal
L1: 1.5uH; SMNR4018_(1616FPS)
MARK1: LOGO; FOX_LOGO_MASK
Q1, Q2: BC847; SOT-23
Q3: BC857; SOT-23
R1: 0R; R_0603_1608Metric_Pad1.05x0.95mm_HandSolder
R2, R7, R27, R30: 10k; R_0603_1608Metric_Pad1.05x0.95mm_HandSolder
R3: 2k; R_0603_1608Metric_Pad1.05x0.95mm_HandSolder
R4: 12k; R_0603_1608Metric_Pad1.05x0.95mm_HandSolder
R5, R6: 10R; R_0603_1608Metric_Pad1.05x0.95mm_HandSolder
R8, R14, R16, R28, R29: 100k; R_0603_1608Metric_Pad1.05x0.95mm_HandSolder
R9, R12, R13, R15, R17, R21, R22, R26, R31, R32, R33: 1k; R_0603_1608Metric_Pad1.05x0.95mm_HandSolder
R10: 180k; R_0603_1608Metric_Pad1.05x0.95mm_HandSolder
R11: 470k; R_0603_1608Metric_Pad1.05x0.95mm_HandSolder
R18, R19, R20: 220k; R_0603_1608Metric_Pad1.05x0.95mm_HandSolder
R23: 1R; R_0603_1608Metric_Pad1.05x0.95mm_HandSolder
R24, R25: 5k1; R_0603_1608Metric_Pad1.05x0.95mm_HandSolder
R34: 330k; R_0603_1608Metric_Pad1.05x0.95mm_HandSolder
RN1, RN2, RN3: 4x470k; R_Array_Convex_4x0603
RN4, RN5, RN6, RN7, RN8: 4x220R; R_Array_Convex_4x0603
SW1: SW_DIP_x04; SW_DIP_SPSTx04_Slide_9.78x12.34mm_W7.62mm_P2.54mm
U1, U2, U3, U5: SRV05-4; SOT-23-6
U4: LN1134A332MR-G; SOT-23-5
U6: 93LCxxB; SOIC-8_3.9x4.9mm_P1.27mm
U7: FT2232H-56Q; QFN-56-1EP_8x8mm_P0.5mm_EP5.6x5.6mm
U8: BL8028; SOT-23-5
U9, U11, U12, U13: 74LVC125; TSSOP-14_4.4x5mm_P0.65mm
U10: 74LVC157A; TSSOP-16_4.4x5mm_P0.65mm
Y1: 12MHz; Crystal_SMD_3225-4Pin_3.2x2.5mm_HandSoldering

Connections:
+3V3: C3.1, C4.1, C21.1, C22.1, C23.1, C26.1, D5.2, D6.2, FB1.2, FB3.2, R2.1, R7.2, R12.2, R13.2, R17.1, U4.5, U6.8, U7.16, U7.36, U7.44, U7.50, U10.11, U10.16, U12.14, U13.14
+5V: C1.1, C2.1, C13.1, C14.1, FB2.1, Q3.2, R29.1, SW1.5, SW1.6, U4.1, U4.3, U8.4
/AC7/LED: D1.1, U7.29
/AD2/TDO: RN7.3, U7.14
/AD2/TDO_RES: RN7.6, U10.7
/AD6/SRST_SENS: RN7.2, U7.19
/AD6/SRST_SENS_RES: RN7.7, U12.8
/AD7/RTCK: RN7.1, U7.20
/AD7/RTCK_RES: RN7.8, U12.11
/BD0_TX_A: RN8.4, RN8.5, U7.32, U11.5
/BD1/RX: RN8.3, U7.33
/BD1/RX_RES: J2.2, RN8.6
/BD2_RTS_A: RN8.2, RN8.7, U7.34, U11.9
/BD3/CTS: RN8.1, U7.35
/BD3/CTS_RES: RN8.8, U13.6
/FTDI/AC0_TRST: U7.22, U9.12
/FTDI/AC1_SRST: U7.23, U11.2
/FTDI/AC2_TRST_OE: U7.24, U9.13
/FTDI/AC3_SRST_OE: U7.25, U11.1
/FTDI/AC4_TMS_OE: U7.26, U9.4
/FTDI/AC5_TDI_OE: U7.27, U9.10
/FTDI/AC6_TCK_OE: U7.28, U9.1
/FTDI/AD0_TCK: U7.12, U9.2
/FTDI/AD1_TDI: U7.13, U9.9, U10.2
/FTDI/AD3_TMS: U7.15, U10.3
/FTDI/AD5_MUX: U7.18, U10.1
/FTDI/BD4_DTR: U7.37, U11.12
/FTDI/EECLK: U6.2, U7.56
/FTDI/EECS: U6.1, U7.1
/FTDI/EEDATA: R3.1, U6.3, U7.55
/FTDI/EEDO: R2.2, R3.2, U6.4
/FTDI/VCORE: C8.1, C11.1, U7.2, U7.31, U7.43
/FTDI/VPHY: C5.1, C6.1, FB1.1, U7.5
/FTDI/VPLL: C7.1, C9.1, FB3.1, U7.9
/OutputBuffers/CMN_OE_IN1: R22.1, U12.1, U12.4, U12.10, U12.13
/OutputBuffers/CMN_OE_IN2: R26.1, U13.1, U13.4, U13.10, U13.13
/OutputBuffers/CMN_OE_OUT: R21.1, U11.4, U11.10, U11.13
/OutputBuffers/TDO_SENS: U10.6, U10.14, U12.6
/OutputBuffers/TMS_SENS: U10.5, U12.3
/OutputBuffers/TMS_UNBUF: U9.5, U10.4
/OutputBuffers/UART_RX_BUF: J2.1, U10.13, U13.3
/PWR_EN: R27.2, U7.17
/RTCK: J4.11, RN2.4, RN5.7
/RTCK_RES: RN5.2, U3.6, U12.12
/RXLED: R33.1, U7.48
/SWD_LED: R15.2, U10.9
/TCK/SWCLK: J4.9, RN1.1, RN4.6
/TCK/SWCLK_RES: RN4.3, U2.1, U9.3
/TDI: J4.5, RN1.3, RN4.7
/TDI_RES: RN4.2, U2.6, U9.8
/TDO/SWO: J4.13, RN2.3, RN5.8
/TDO/SWO_RES: RN5.1, U3.4, U12.5
/TMS/SWDIO: J4.7, RN1.2, RN4.5
/TMS/SWDIO_RES: RN4.4, U2.3, U9.6, U12.2
/TXLED: R32.1, U7.49
/UART_CTS: J4.20, RN3.1, RN6.6
/UART_CTS_RES: RN6.3, U1.1, U13.5
/UART_DTR: J4.18, RN3.3, RN6.7
/UART_DTR_RES: RN6.2, U1.6, U11.11
/UART_RTS: J4.16, RN2.1, RN5.6
/UART_RTS_RES: RN5.3, U3.1, U11.8
/UART_RX: J4.17, RN3.4, RN6.8
/UART_RX_RES: RN6.1, U1.4, U13.2
/UART_TX: J4.19, RN3.2, RN6.5
/UART_TX_RES: RN6.4, U1.3, U11.6
/~nSRST~/~RST~: J4.15, RN2.2, RN5.5
/~nSRST~/~RST~_RES: RN5.4, U3.3, U11.3, U12.9
/~nTRST~: J4.3, RN1.4, RN4.8
/~nTRST~_RES: RN4.1, U2.4, U9.11
GND: C1.2, C2.2, C3.2, C4.2, C5.2, C6.2, C7.2, C8.2, C9.2, C10.2, C11.2, C12.2, C13.2, C14.2, C16.2, C18.2, C19.2, C20.2, C21.2, C22.2, C23.2, C24.2, C25.2, C26.2, D2.1, D3.1, J1.A1, J4.4, J4.6, J4.8, J4.10, J4.12, J4.14, Q1.2, Q2.2, R1.2, R4.2, R8.1, R16.1, R18.1, R19.1, R21.2, R22.2, R24.2, R25.2, R26.2, R28.2, RN1.5, RN1.6, RN1.7, RN1.8, RN2.5, RN2.6, RN2.7, RN2.8, RN3.5, RN3.6, RN3.7, RN3.8, SW1.7, SW1.8, U1.2, U2.2, U3.2, U4.2, U5.2, U6.5, U7.10, U7.21, U7.41, U7.45, U7.57, U8.2, U9.7, U10.8, U10.10, U10.15, U11.7, U12.7, U13.7, U13.9, U13.12, Y1.2, Y1.4
unnamed: C10.1, U7.3, Y1.1
unnamed: C12.1, U7.4, Y1.3
unnamed: C17.2, R10.2, R11.2, R18.2, R19.2, R20.2, R34.2, U8.5
unnamed: C25.1, R4.1, U7.6
unnamed: D1.2, R12.1
unnamed: D2.2, R13.1
unnamed: D3.2, R15.1
unnamed: D4.1, Q1.3
unnamed: D4.2, R17.2
unnamed: D5.1, R33.2
unnamed: D6.1, R32.2
unnamed: FB2.2, J1.A4, U5.4, U5.5
unnamed: J1.A5, R24.1
unnamed: J1.A6, J1.B6, R5.2, U5.1
unnamed: J1.A7, J1.B7, R6.2, U5.6
unnamed: J1.B5, R25.1
unnamed: J1.S1, R1.1
unnamed: J2.3, U10.12
unnamed: J4.1, J4.2, R23.2
unnamed: L1.1, U8.3
unnamed: Q1.1, R14.1, R16.2
unnamed: Q2.1, R27.1, R28.1
unnamed: Q2.3, R30.2
unnamed: Q3.1, R29.2, R30.1
unnamed: Q3.3, R31.1
unnamed: R5.1, U7.8
unnamed: R6.1, U7.7
unnamed: R7.1, U7.11
unnamed: R9.2, SW1.3
unnamed: R10.1, SW1.1
unnamed: R11.1, R34.1, SW1.2
unnamed: R8.2, R9.1, R31.2, U8.1
VCC: C16.1, C17.1, C18.1, C19.1, C20.1, C24.1, L1.2, R14.2, R20.1, R23.1, SW1.4, U1.5, U2.5, U3.5, U9.14, U11.14
